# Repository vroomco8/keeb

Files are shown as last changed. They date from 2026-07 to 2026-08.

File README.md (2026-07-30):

# ⌨️ KEYBOARD

*A custom mechanical keyboard, designed from the switches down.*



</div>

---

## Overview

This repository documents the design and build of a fully custom keyboard from scratch.

> [Thought I could get out of my comfort zone and try something I haven't done before. I'm mainly a CS guy, but have always wanted to design and make something for myself!]

Want to note that everything below is entirely conceptual. I have not researched at all about specific electronic parts nor have I explored options with 3d printing and etc. All of the stuff I am saying is coming straight from the little information I know about assembling a keyboard

| | |
|---|---|
| **Layout** | 97% (104-3) |
| **Switches** | Cherry MX (Red) |
| **Case material** | 3D-printed atm, maybe switch to heavy material afterwards |
| **Mounting style** | Tray Mount |
| **Microcontroller** | Raspberry Pi Pico |
| **Firmware** | QMK |

---

## ✨ Features

- [x] RGB Implementation (toggleable)
- [x] Rotary Encoder (Volume, pause/play)
- [x] OLED Screen (Cool displays / Current Spotify / etc...)

---

## 🧩 Design

Currently, I have a Lenovo SK-8815 released in 2004. This thing is older than me (and could be classified as a antique), but it is reliable and I love it. Been using it since 5th grade, and has never failed me. 
However, it can be improved. This organization, HackClub, allows me to sort of improve on its design in ways that I sort of want, through OLED screens and rotary encoders, and more.

For that reason, I want a 100% keyboard with a similar configuration to my old keyboard, but with different switches, RGB(?), wireless, and more if I can fit it within the given timeframe. 
Kinda like this, except the empty space above the numpad has a rotary encoder and an OLED screen


### Some Images





---

## 🗂️ Repository Structure

```
├── pcb/          # KiCad project, schematics, gerbers
├── case/         # CAD files, STLs, technical drawings
├── firmware/     # QMK firmware for the keyboard
├── bom.csv/      # da bill of materials (please approve me)
├── WORKLOG/      # da diary entries of my progress
└── README.md
```

## 🚧 Roadmap

- [x] Making GitHub Repo
- [x] Planning Your Keyboard
- [x] Designing the PCB
- [x] Designing the Case
- [x] Writing Firmware
- [x] Adding Extra Parts
- [ ] Submitting
---

PLEASE APPROVE ME

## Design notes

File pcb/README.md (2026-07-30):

### This folder contains files related to the PCB (KiCad Work)

The final PCB is keeb-v5. All of my CAD files are based off the DRX file generated from the keeb-v5.

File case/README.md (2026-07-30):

### This folder contains all of my CAD files. 

This is the public Onshape file: https://cad.onshape.com/documents/8c70046051d18efdf76ca640/w/53351b508ead0cbaf662196b/e/99ffe23963ec41a247280fbc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

Ignore the missing key. i missed adding it to the PCB model and I got too lazy to get another step file afterwards. Additionally, the holes for the OLED and rotary dial may not be updated, but for the files in these folders they are. 

Also, please note that there were two versions of the CAD. v1 did not work, so v2 was the only one that was uploaded (check worklog as to why ;D)

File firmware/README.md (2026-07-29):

### This folder contains all of the firmware for the keyboard

I used the QMK guide, as it has a lot more support for RGB matrices and encoders, as well as very clear documentation.
Also, I am a complete noob at this, so everything I'm doing is copied straight from the documentation and modified to fit whatever I have.

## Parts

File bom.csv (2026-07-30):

Name | Notes | Qty | Price/Unit | Total | Running Total | Link
Gateron Cherry MX Brown Switches | keyswitches, pack of 108 | 1 | $29.99 | $29.99 | $29.99 | https://www.amazon.com/Zjmehty-Switches-Mechanical-Pre-Lubed-Pin-Enhanced/dp/B0CF8DWDGF?rnid=41941986011
0402 500 Resistor | resistors | 101 | $0.02 | $2.02 | $32.01 | https://jlcpcb.com/partdetail/YAGEO-RT0402FRE07500RL/C6460545
Raspberry Pi Pico | MCU | 1 | $0.99 | $0.99 | $33.00 | https://www.aliexpress.us/item/3256808882158444.html?curPageLogUid=cKROVG7c192z
EC11 Rotary Encoders | for volume, etc | 1 | $1.37 | $1.37 | $34.37 | https://www.aliexpress.us/item/3256805796819763.html?curPageLogUid=JMbjUrnAcT9o
1N4148 diode | capacitors | 3 | $2.02 | $6.06 | $35.74 | https://www.aliexpress.us/item/3256806058794623.html?curPageLogUid=PUp6uTBiT1El
SK6812 mini e LEDs | for each switch, RGB lightin. packs of 100 | 1 | $4.50 | $4.50 | $41.80 | https://www.aliexpress.us/item/3256805007401420.html?curPageLogUid=bFY8ZeYEj1Qn
0.91" OLED | OLED screen | 1 | $2.24 | $2.24 | $46.30 | https://www.aliexpress.us/item/3256809902820804.html?srcSns=sns_Copy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
Durock MX Stab kit | Stabilizers | 1 | $25.99 | $25.99 | $48.54 | https://www.amazon.com/DUROCK-Stabilizers-Translucent-Keyboard-Mechanical/dp/B0B2RVKH2L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
Keycaps | Keycap kit, for 100% | 1 | $17.99 | $17.99 | $74.53 | https://www.amazon.com/Keycaps-Doubleshot-Percent-Mechanical-Keyboard/dp/B0D1QVD55F
PCB | JLCPCB | 1 | $32.30 | $32.30 | $92.52 | quote from uploading
Case | JLCPCB | 1 | $32.96 | $32.96 | $124.82 | quote from uploading
Total |  |  |  |  | $157.78

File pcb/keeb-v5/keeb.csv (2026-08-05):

Id | Designator | Footprint | Quantity | Designation | Supplier and ref
1 | A1 | RaspberryPi_Pico_Common_THT | 1 | RaspberryPi_Pico
2 | C1, C2, C3, C4, C5, C6, C7, C8, C9, C10, C11, C12, C13, C14, C15, C16, C17, C18, C19, C20, C21, C22, C23, C24, C25, C26, C27, C28, C29, C30, C31, C32, C33, C34, C35, C36, C37, C38, C39, C40, C41, C42, C43, C44, C45, C46, C47, C48, C49, C50, C51, C52, C53, C54, C55, C56, C57, C58, C59, C60, C61, C62, C63, C64, C65, C66, C67, C68, C69, C70, C71, C72, C73, C74, C75, C76, C77, C78, C79, C80, C81, C82, C83, C84, C85, C86, C87, C88, C89, C90, C91, C92, C93, C94, C95, C96, C97, C98, C99, C100, C101 | C_0402_1005Metric | 101 | 100nF
3 | D1, D2, D3, D4, D5, D6, D7, D8, D9, D10, D11, D12, D13, D14, D15, D16, D17, D18, D19, D20, D21, D22, D23, D24, D25, D26, D27, D28, D29, D30, D31, D32, D33, D34, D35, D36, D37, D38, D39, D40, D41, D42, D43, D44, D45, D46, D47, D48, D49, D50, D51, D52, D53, D54, D55, D56, D57, D58, D59, D60, D61, D62, D63, D64, D65, D66, D67, D68, D69, D70, D71, D72, D73, D74, D75, D76, D77, D78, D79, D80, D81, D82, D83, D84, D85, D86, D87, D88, D89, D90, D91, D92, D93, D94, D95, D96, D97, D98, D99, D100, D101, D102 | D_DO-35_SOD27_P7.62mm_Horizontal | 102 | 1N4148
4 | LED1, LED2, LED3, LED4, LED5, LED6, LED7, LED8, LED9, LED10, LED11, LED12, LED13, LED14, LED15, LED16, LED17, LED18, LED19, LED20, LED21, LED22, LED23, LED24, LED25, LED26, LED27, LED28, LED29, LED30, LED31, LED32, LED33, LED34, LED35, LED36, LED37, LED38, LED39, LED40, LED41, LED42, LED43, LED44, LED45, LED46, LED47, LED48, LED49, LED50, LED51, LED52, LED53, LED54, LED55, LED56, LED57, LED58, LED59, LED60, LED61, LED62, LED63, LED64, LED65, LED66, LED67, LED68, LED69, LED70, LED71, LED72, LED73, LED74, LED75, LED76, LED77, LED78, LED79, LED80, LED81, LED82, LED83, LED84, LED85, LED86, LED87, LED88, LED89, LED90, LED91, LED92, LED93, LED94, LED95, LED96, LED97, LED98, LED99, LED100, LED101 | LED_6028R | 101 | SK6812MINI-E
5 | R1 | R_0402_1005Metric | 1 | 500
6 | SBackspace1, SEnter1, SLShift1, Sn1, SnEnter1, SnPlus1, SRShift1 | STAB_MX_2u | 7 | MX_stab
7 | SSpace1 | STAB_MX_6.25u | 1 | MX_stab
8 | SW'1, SW,1, SW.1, SW/1, SW1, SW2, SW3, SW4, SW5, SW6, SW7, SW8, SW9, SW10, SW;1, SWa1, SWAsterisk1, SWb1, SWBackspace1, SWc1, SWCapsLock1, SWd1, SWDelete1, SWDown1, SWe1, SWEnd1, SWEnter1, SWEscape1, SWF1, SWF2, SWF3, SWF4, SWf5, SWF6, SWF7, SWF8, SWF9, SWF10, SWF11, SWF12, SWF13, SWForwardSlash1, SWg1, SWh1, SWHome1, SWi1, SWInsert1, SWj1, SWk1, SWl1, SWLAlt1, SWLCtrl1, SWLeft1, SWLShift1, SWLWindows1, SWm1, SWMinus1, SWn1, SWn2, SWn3, SWn4, SWn5, SWn6, SWn7, SWn8, SWn9, SWn10, SWn11, SWnEnter1, SWnMinus1, SWnPeriod1, SWnPlus1, SWNumLock1, SWo1, SWOptions1, SWp1, SWPageDown1, SWPageUp1, SWPlus1, SWq1, SWr1, SWRAlt1, SWRCtrl1, SWRight1, SWRShift1, SWRWindows1, SWs1, SWSpace1, SWt1, SWTab1, SWTilda1, SWu1, SWUp1, SWv1, SWw1, SWx1, SWy1, SWz1, SW[1, SW\1, SW]1 | SW_MX_1u | 101 | SW_Push
9 | SW11 | RotaryEncoder_Alps_EC11E-Switch_Vertical_H20mm | 1 | RotaryEncoder_Switch
10 | U1 | ER_OLEDM0.91_1x-I2C | 1 | ER_OLEDM0.91_1x-I2C

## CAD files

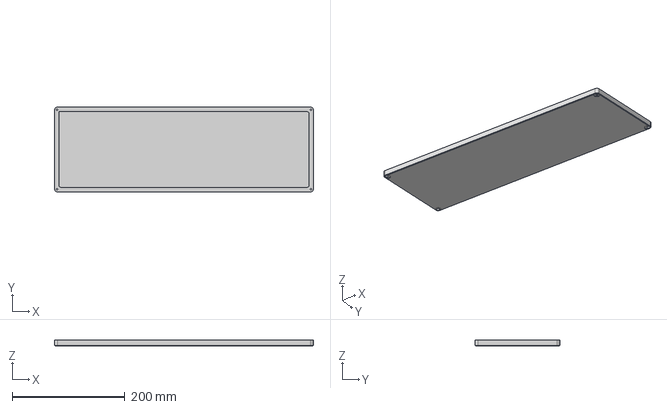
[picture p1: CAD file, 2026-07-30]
case/Keyboard v2 - Bottom Plate.step
459.8 x 150.3 x 10.0 mm

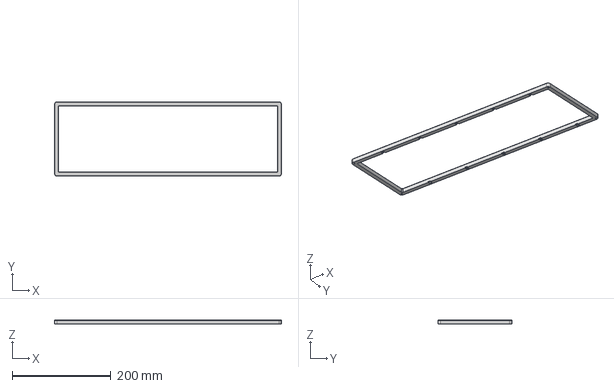
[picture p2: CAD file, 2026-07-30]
case/Keyboard v2 - Top Plate.step
459.8 x 150.3 x 8.50 mm

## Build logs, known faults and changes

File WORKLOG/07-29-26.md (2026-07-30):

### 2026-07-29

~2.5 hrs: Finished up the firmware. Finished bom. Polished PCB.

I realized that 2.25u and 2.75u stabilizers don't exist, so I replaced those with 2u stabilizers on the PCB, and then on the CAD. Also fixed a couple of errors pointed out by the DRC on the PCB. In terms of the CAD, I think I want to see the actual PCB and get a size of it first, before I decide to print out the CAD. I feel that way it would be easier. 
Formatted and updated all of the README.md as well.



Tomorrow, I plan on submitting my git repository.

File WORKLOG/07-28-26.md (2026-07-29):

### 2026-07-28

~2hrs: Worked on the keyboard firmware on the QMK firmware. The RMK firmware didn't have the proper documentation regarding RGB matrix and OLED screens, but the QMK did. It even has a graphical interface!!!

The code is still very rough, will refine over the next couple of days. 





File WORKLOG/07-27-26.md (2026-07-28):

### 226-07-27

~1.5 hrs: Got started working on the firmware

Unfortunately, the guide that was provided does not include support for : LEDs (specifically a chain of them) and an OLED screen. This means that I will have to figure it out without using whatever RMK is, although it is quite unfortunate. 

I will look into/research this in the following couple of days. 


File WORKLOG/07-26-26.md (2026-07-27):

### 2026-07-26

~2hrs: It's on Onshape, at it looks like it fits!  

There are still some tweaks I need to do: 
- add holes for the led screen and rotary encoder
- extend the bottom
- verify whether there are any clearance issues.

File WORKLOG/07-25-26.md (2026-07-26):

### 2026-07-25

~3hrs: "Finished" CAD for the actual keyboard based on my PCB. Now, finished is in quotes because I have no idea whether it will fit or not, because I need to test that in Onshape (D:). Uploading the full PCB model to Fusion 360 blows everything up and causing Fusion to crash over and over. 
Onshape is the only tool which has been able to load the entire PCB on the website. However, I have no idea how to assemble componenets together in onshape, so I gotta watch tutorials. Thats for another day though. Additionally, I don't know how to add a rotary dial and an LED screen on my CAD. 
I don't know if I need to cut out something on my front plate or not, or something similar, but yea thats the predicament I'm in at the moment. I'll add pictures of my Fusion 360 work tomorrows because I kinda accidentally closed Fusion without taking pictures.

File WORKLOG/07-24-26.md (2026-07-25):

### 2026-07-24



~1hr I started working on the actual CAD for the case. Unfortunately, me being a dumbo the schematic generated by ai03 is not the same as the PCB i made on kicad. So, I exported the Kicad files as a drx file and imported into fusion to get the actual plate, and holy that slowed down fusion a lot. It is not happy with me, but whatever. 

Currently, I am building the top plate. Unfortunately, I forgot to hit record on lapse so I have no idea how much time this took, but it felt like forever. I'm just gonna keep it short and keep it at 1 hr.

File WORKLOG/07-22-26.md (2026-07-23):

### 2026-07-22

~2.5hrs: Started working on case. Found a really nice guide on github about designing the case, and I followed it. I verified with the Kicad drx file to check whether everything was the correct size or not, and it appears to be!



Now some issues: 
- I didn't add a hole for the encoder or the OLED screen. This is because the template I used to make the cutouts for each of the keys was provided by https://www.keyboard-layout-editor.com/#/ and https://kbplate.ai03.com/. There isn't a place to add space for a OLED screen or a rotary encoder
- Guide doesn't cover how to add USB holes, or whether to use heatset inserts or not. I just used whatever screws they said to use, which are M2 and M3 screws. This potentially means I need to spend more money on them
- I don't know whether the space inside the case is enough to fit the PCB. I know that the size is right, but the PCB may be bigger or smaller, which means I need to extend the sketch. 

All of these issues just means more work for me, but it's a lot more doable. THANK GOD KICAD CAN EXPORT THINGS INTO A DRX FILE. FUSION 360 IS SO MUCH MORE EASIER TO WORK WITH THAT ONSHAPE. 

Guide I used: https://github.com/axolstudio-ca/Introductory-Guide/wiki/0.-A-Intro-to-Keyboard-Designing

Its very useful in terms of designing and such, giving the proper images.

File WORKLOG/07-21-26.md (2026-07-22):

### 2026-07-21

~10 min: Finalized the PCB. Had some ratsnets issues and such, but all good now (according to DRC) Now getting started on the CAD


I tried starting on the CAD already yesterday, both on Fusion and Onshape. I tried uploading the PCB into Fusion and that thing took hours and hours of loading. I don't even think it loaded, so I gotta learn how to use onshape now. Thats the plan for today!

~1hr 20 min: CAD is easy when you are familiar with the tools. Onshape is slow, messy controls, and also very, very confusing to use. Fusion is so easy, just left clicking a part and adding it to a component. Onshape has different names for things, and also weird UI all over the screen. 
It's so confusing that I had to search up how to resize a rectangle in the sketch tool. Like Fusion makes ts so easy and onshape you gotta use another, completely separate tool just to resize something? 

If only I could upload the PCB CAD model into Fusion 😭

Anyways, I got started on the CAD, and the UI makes me wanna cry. The docs are not that helpful, as they only have text instructions. Images here woulda helped the most. This will definetely be the most time consuming part of the keyboard because I have no idea about the measurements/clearances needed for the PCB. 
All I can rely on is the one screenshot about the "cheatsheet" of different mounts. Bro its just a pic with text on it, it doesn't give any clarification about measurements, how I could implement it, and such. I wish myself good luck in the future. 

I also absolutely abhore the fact that uploading a part onto onshape takes 1. forever and 2. not that straightforward to add to a assembly. This is gonna be the most confusing part of the entire project. 

what also sucks is that i don't have a physical sizing of the board, so i don't know how i could possibly size it to my sepcifications. What if i make it too thick? too thin? can there even be a too thin option? these are all valid concerns in my mind, and all things that could potentially screw up the entire project, but hell everything i've been doing has been off the information that was on the docs, given to me on slack, or my own assumptions. All i could do is walk forward, either to my demise or success. :(



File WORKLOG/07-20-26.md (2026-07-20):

### 2026-07-20

~7.5hrs: Redid all of the wiring such that the LEDs are now on the back of the board. I thought it would be easier to start from scratch. Also got some feedback from slack saying that I should make the +5V trace thicker and also put another trace in the middle so the voltage doesn't drop, which I did. It feels a little bit more messier now, but it is what it is.



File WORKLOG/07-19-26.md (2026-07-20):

### 2026-07-19

~2.5 hrs: Finished the PCB (hopefully) I asked a couple clarifying questions in slack, but I completed all the PCB steps in the actual docs, leaving me with this result: 

My main concern at the moment is the LEDs (as usual). I have 101 LEDs all being wired to one +5V pin on the Pico in a daisy chain format. That means that technically, all 101 pins are being driven from one wire trace, which is not ideal. According to online, it says I need like a 3mm or greater trace to support 101 LEDs in a daisy chain. 
At the moment, I just connected the LEDs so that it somewhat looks like a cycle/loop . I think this is okay, but I'm not too sure so I asked questions about it in slack. 
The keeb-help channel is very, very slow in terms of response times, so I also asked it in the electronics channel. Hopefully someone can answer all of my questions :D

~3.5 hrs: Finished the PCB designing. Added some mountains and space stuff because i thought it was cool. still no response in slack 😭




~2 hrs: Started working on CAD until found issue: The LEDS and the switches are interfering. If I solder the LEDS, the switches have no place in order to sit properly onto the plate. *sigh* This means I need to move the LEDs down such that they are in between each switch so that they could be wired properly. Looking at the PCB, this does appear to be possible. However: I need to work on the wiring again. I don't wanna touch the wiring i spent so long, but i have. This is incredibly unfortunate. 




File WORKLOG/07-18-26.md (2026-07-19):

### 2026-07-18

~9hrs (yes, it was 9hrs you can look at lapse): Finished wiring? No more ratsnets and such, so hopefully finished. I'm gonna keep reading the guide to see what else I need to do.


~1hr verified with the DRC that there are indeed some changes that needed to be made. Errors included some mismatches with the schematic, which I fixed, but there is a warning that I want to look into titled "Silkscreen clipped by solder mask" The silkscreen text is beeing clipped out by the wire. Therefore, either I completely remove the silkscreen text or I edit it such that it fits into board without interfering with the traces. I'm thinking I delete it and add some cool art, I'll look at other people's boards to see what they did. 


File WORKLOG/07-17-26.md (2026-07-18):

### 2026-07-17

~2.5hrs
Worked on tracing. It's a little messy at the moment, but it does work column/row wise. However, I need to route the GND and the LEDs first because that requires the +5V and the GND, which are bigger traces, mm wise. 


~2.5hrs
Back to square one. I messed up, had to delete all the wires. Found a guide, very thankful too daredllama for their feedback on wiring. I did not know about different size wires or the difference between +5, 3.3, etc. Have a game plan for tomorrow, and will work on it!


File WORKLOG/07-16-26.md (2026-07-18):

### 2026-07-16

~2.5hrs  Restarting, but with more planning!

The wiring is hell, so I went back to the drawing board to see if there is a better way to wire everything together this is the way that I decided to do it, so I need to update the schematic and the PCB


Updating PCB schematic: 

I updated the schematic using changing the keys related to the grid and also making sure that everything is named correctly. Also need to ignore the naming conventions, as it kinda got screwed ever with the automatic naming tool. 



~3.5 jrs Updating PCB:

I updated the PCB layout with this new layout. It still is really messy and I need to work out a few kinks here are there. Hopefully it turns out better. Thanks to daredllama, I got a pretty good idea on things I need to improve on, and potentially new methods in terms of wiring (i.e flipping components on the board itself)


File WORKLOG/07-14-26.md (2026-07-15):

### 2026-07-12 

~1.5hrs
Added LED chain, OLED screen, and one rotary encoder to the schematic. Next step is working on the PCB editor itself. Also I completely am doing this from no where, using other people's examples to understand how to wire/connect everything. It still is a little confusing, especially since no one has done a 100% keyboard before with the amount of things that I have on there. 
I hopefully wired everything correctly, and I asked a question in Slack because I wasn't sure whether the LED chain is connected to a 3.3v or 5v (the VDD port on the chain). Hopefully they can clear anything I did wrong easily. 



A big thanks to the brew-keeb project, as that has been my one and only guide light where the documentation falls short. If anyone is reading through this to make their own keyboard, please don't follow my steps. Everything I'm doing comes straight from the documentation/brew-keeb. I have zero experience in PCB design and manufacturing. 

~1.5hrs
Added LED chain, OLED screen, and one rotary encoder to the actual PCB. It looks really, really messy, so hopefully it's not too difficult to wire. 

One thing I am concerned about is the LED chain. At the moment, I am copying what the brew-keeb project did but there are some concerns:

1. The brew-keeb project only uses 22 LEDS. I am using 101 LEDS. This means I probably am going to need significantly more power, which is what another repository, sudo-apt-install-65 does, using a 5v instead of 3.3v. But again, they are using 68 LEDS. I'm almost doubling the amount, so I have no idea whether I have done it correctly or not.
2. The wiring of the LED chain in my mind is like a chain. So, I put the LEDS in like a snake pattern on the PCB. I'm going to try to get started on the wiring, but am saving a copy of my work to the github in case I screw up. 

~1.5hrs
Wiring Hell. I had to rearrange some of the rows in order for it to be "cleanly" wireable on the schematic. This may cause future software problems, but hopefully not. When I get to the columns there's just not enough space for all of the wires to cleanly wire everything up. This may mean I need to rearrage some keys in the schematic, which hopefully isn't too much of a pain




This gonna get real messy real fast.

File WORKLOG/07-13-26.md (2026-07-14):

### 2026-07-12 
~30min
Setup Lapse in order to log a sort of timelapse of my work. Apparently necessary in order for the grant to be approved according to the Slack. Better safe than sorry!

~4hrs
I had to modify the PCB schematic after receiving feedback from Slack. Before I had around 21 columns and 5 rows, meaning I was using 26 GPIO pins, which is basically all of the raspberry GPIO pins. Thanks to some friendly advice on Slack, I was told to modify the grid such that it is a 'square' so I can use the fewest possible GPIO pins.

Now, I have around 13 columns and 8 rows, meaning I'm only using 21 GPIO pins, meaning I have some to spare for the LEDS, a rotary encoder, and an OLED screen (yippee!)

Afterwards, I worked on the PCB itself. Here I really wished that the guide is more specific on certain points. For example, the format. When placing components, I tried my best to make them look aligned and in a grid like shape, but in my mind I'm sure that some of the keys are intersecting. I'm probably going to ask Slack for advice after this, as well as feedback on my current board.


Some concerns: 

1. When modifying the grid, I had to move the entire numpad over to cut the number of columns and squish everything into the space I had. However, I'm trying to think about wiring. Some of the keys are not exactly "nicely placed" in the grid, which in my mind routing may be a little difficult. I may have to restart from scratch in case, but this will be a future problem
2. When adding stabilizers, I realized that a 100% keyboard was quite different from the keyboard used in the guide (who splits their space key into three different space keys???) This means that I have different sized stabilizers for different keys. For example, the space key is 6.25mu, the right shift key is 2.75mu and so on, while the guide only uses 2mu (I'm assuming for simplicity) I'm planning on asking slack if the current way I'm doing it is okay or not.
3. I need to add the rotary encoder and the LEDS (sob). This probably means I will have to go back to the schematic and edit it such that it has those components in. I wish that those objects were in the guide as I went along, but I will probably re-visit them once I have the base model yknow
4. I hate the empty space added by the Raspberry Pi PICO. I wish there was a way to put switches over it so it's nicely hidden OR put like an OLED there so it looks cool. I'll figure something out, so it is a future problem

This is just a quick update for now, maybe will do stuff later today. 
***
~1.5hrs
Alright, as of 11:53 PM, I redid the grid with the alignments. I guess I missed a small part of the guide where it said to make a custom grid such that all the elements are aligned, which actually worked perfectly. Updated grid: 

It doesn't look much different, but zooming in to all of the lines, it is very accurate, and none of the keys overlap with each other which is wonderful. 

Will start the next step (wiring) tomorrow. Hopefully I don't have to redo everything!
So far, this is my main concern, as it is not as clean as the rest of the keyboard

It's seems really messy, hopefully the wiring is manageable.

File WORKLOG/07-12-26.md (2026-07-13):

### 2026-07-12 

~1.5hrs
Started on the KiCAD schematic. Got a basis down, but the guide isn't all that clear about what to do with the stabilizers. Looking at other repos from other people in the Slack, it doesn't appear that they put the stabilizers in their schematics, so I just full on ignored it. Asked a question in slack and hopefully they respond with clarifications on whether my schematic is correct. 


~1.5hrs
Worked on initial draft of the BOM, planning out switches, diodes, etc all according to the guide. Since I'm making a 100% keyboard, I'm aiming for around 104 keys (standard). The Raspberry PI Pico supports that many (11x11 matrix, or less) so I should be fine with that. I planned out a rotary encoder and RGB (Aliexpress for the win)

~1.5hrs
Started the repository. Updated the README about my plans, and started sketching out the type of keyboard I want. Read the full documentation to make sure that I am aware about what the future steps are. I want a 100% keyboard but the guide only outlines a 60% keyboard, which is a little scary but hey I'm doing this to get out of my comfort zone.

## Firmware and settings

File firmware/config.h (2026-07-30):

//OLED settings
#define I2C_DRIVER I2CD1
#define I2C1_SDA_PIN GP27
#define I2C1_SCL_PIN GP28

//RGB
#define WS2812_DI_PIN GP26
#define RGBLIGHT_LED_COUNT 101

#define RGBLIGHT_MODE_RAINBOW_MOOD
#define RGBLIGHT_MODE_RGB_TEST
#define RGBLIGHT_MODE_TWINKLE
#define RGBLIGHT_LIMIT_VAL 100

#define RGBLIGHT_DEFAULT_MODE RGBLIGHT_MODE_RAINBOW_MOOD


//encoders
#define ENCODER_A_PINS { GP21, GP22 }

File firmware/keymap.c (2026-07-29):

// Copyright 2023 QMK
// SPDX-License-Identifier: GPL-2.0-or-later

#include QMK_KEYBOARD_H

const uint16_t PROGMEM keymaps[][8][13] = {
    [0] = LAYOUT(
        KC_ESC,  KC_F1,   KC_F2,   KC_F3,   KC_F4,   KC_F5,   KC_F6,   KC_F7,   KC_F8,   KC_F9,   KC_F10,  KC_F11,  KC_F12, // ROW0
        KC_GRV,  KC_1,    KC_2,    KC_3,    KC_4,    KC_5,    KC_6,    KC_7,    KC_8,    KC_9,    KC_0,    KC_MINS, KC_EQL, // ROW1
        KC_TAB,  KC_Q,    KC_W,    KC_E,    KC_R,    KC_T,    KC_Y,    KC_U,    KC_I,    KC_O,    KC_P,    KC_LBRC, KC_RBRC, // ROW2
        KC_CAPS, KC_A,    KC_S,    KC_D,    KC_F,    KC_G,    KC_H,    KC_J,    KC_K,    KC_L,    KC_SCLN, KC_QUOT, KC_ENT, // ROW3
                 KC_LSFT, KC_Z,    KC_X,    KC_C,    KC_V,    KC_B,    KC_N,    KC_M,    KC_COMM, KC_DOT,  KC_SLSH, KC_RSFT, // ROW4
        KC_LCTL, KC_LGUI, KC_LALT, KC_P0,   KC_P3,   KC_P2,   KC_P1,   KC_NUM,  KC_SPC,  KC_RALT, KC_RGUI, MO(1),   KC_RCTL, // ROW5
        KC_BSLS, KC_MPLY, KC_PPLS, KC_PDOT, KC_P6,   KC_P5,   KC_P4,   KC_PSLS, KC_RIGHT,KC_LEFT, KC_PGDN, KC_END,  KC_DEL, // ROW6
        KC_BSPC,          KC_PMNS, KC_PENT, KC_P9,   KC_P8,   KC_P7,   KC_PAST, KC_DOWN, KC_UP,   KC_PGUP, KC_HOME, KC_INS // ROW7
    ),

    [1] = LAYOUT(
        _______,  _______, _______, _______, _______, _______, _______, _______, _______, _______, _______, _______, _______, // ROW0
        _______,  _______, _______, _______, _______, _______, _______, _______, _______, _______, _______, _______, _______, // ROW1
        _______,  _______, _______, _______, _______, _______, _______, _______, _______, _______, _______, _______, _______, // ROW2
        _______,  _______, _______, _______, _______, _______, _______, _______, _______, _______, _______, _______, _______, // ROW3
                  _______, _______, _______, _______, _______, _______, _______, _______, _______, _______, _______, _______, // ROW4
        _______,  _______, _______, _______, _______, _______, _______, RM_TOGG, _______, _______, _______, _______, _______, // ROW5
        _______,  _______, _______, _______, _______, _______, _______, _______, UG_NEXT, UG_PREV, _______, _______, _______, // ROW6
        _______,           _______, _______, _______, _______, _______, _______, RM_VALD, RM_VALU, _______, _______, _______ // ROW7
    ),

};

#if defined(ENCODER_MAP_ENABLE)
const uint16_t PROGMEM encoder_map[][NUM_ENCODERS][NUM_DIRECTIONS] = {
    [0] = { ENCODER_CCW_CW(KC_VOLD, KC_VOLU)  },
};
#endif

#ifdef OLED_ENABLE
// logo function, mess around in QMK to make a custom logo!
bool oled_task_user(void) {
    // Host Keyboard Layer Status
    oled_write_P(PSTR("Layer: "), false);

    switch (get_highest_layer(layer_state)) {
        case 0:
            oled_write_P(PSTR("Default\n"), false);
            break;
        case 1:
            oled_write_P(PSTR("LEDs\n"), false);
            break;
        default:
            // Or use the write_ln shortcut over adding '\n' to the end of your string
            oled_write_ln_P(PSTR("Undefined"), false);
    }

    // Host Keyboard LED Status
    led_t led_state = host_keyboard_led_state();
    oled_write_P(led_state.num_lock ? PSTR("NUM ") : PSTR("    "), false);
    oled_write_P(led_state.caps_lock ? PSTR("CAP ") : PSTR("    "), false);
    
    return false;
}
#endif

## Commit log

2026-07-13 Create WORKLOG for project tracking
    Added a build diary to track progress and decisions.
2026-07-13 Create WORKLOG.md for project documentation
    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
2026-07-13 Update README.md to reflect work in progress
    Removed placeholder text for PCB and Case sections in README.
2026-07-13 Document work on BOM and keyboard design
    Added another entry for July 12, 2026, detailing work on the BOM and keyboard planning.
2026-07-13 Add PCB image to README
    Added an image to the PCB section in the README.
2026-07-13 Add worklog entry for July 12, 2026
    Document progress on KiCAD schematic, BOM, and repository setup for keyboard project.
2026-07-14 Revise PCB status and update WORKLOG directory
    Updated PCB section to indicate it is currently working and modified the WORKLOG path.
2026-07-14 Add worklog entry for PCB design updates
    Documented work progress on PCB design and modifications, including GPIO pin usage and layout concerns. Added notes on challenges faced and future considerations for components.
2026-07-14 Revise grid alignment and document updates
    Updated the grid alignment and documented changes made to the schematic. Added images to illustrate the updated grid accuracy.
2026-07-14 Document wiring concerns and add images
    Added concerns about wiring cleanliness and images.
2026-07-15 Revise PCB and project status in README
    Updated section headings and added TODO notes for PCB, Case, and Firmware.
2026-07-15 Update worklog with schematic progress and challenges
    Document progress on adding components to the schematic and seeking help on wiring.
2026-07-15 Update WORKLOG with PCB design progress and concerns
    Documented progress on PCB design including LED chain, OLED screen, and rotary encoder. Addressed concerns regarding power requirements and wiring.
2026-07-15 Add README for PCB folder
2026-07-15 Update worklog with LED chain concerns and wiring notes
    Document concerns about LED chain power requirements and wiring challenges. Include images for reference.
2026-07-17 Add work log entry for July 16, 2026
    Documented work progress on July 16, 2026, including planning and schematic updates.
2026-07-18 Revise schematic and PCB layout for better clarity
    Updated schematic and PCB layout with new design considerations and improvements.
2026-07-18 Add work log for tracing progress on July 17, 2026
    Added work log entry for July 17, 2026, detailing tracing progress and requirements for routing GND and LEDs.
2026-07-18 Revise WORKLOG with tracing updates and reflections
    Updated work log with progress and setbacks on tracing. Added images and reflections on wiring feedback.
2026-07-19 Add work log entry for July 18, 2026
    Documented work log for July 18, 2026, detailing 9 hours of work on wiring.
2026-07-19 Document worklog updates and DRC findings
    Verified changes with DRC and addressed schematic mismatches. Considering options for silkscreen text adjustment.
2026-07-20 Add work log entry for July 19, 2026
    Documented work on PCB design and concerns regarding LED wiring.
2026-07-20 Update worklog with PCB design and LED notes
    Documented progress on PCB design and LED wiring concerns.
2026-07-20 Update worklog with PCB and CAD progress
    Documented progress on PCB design and CAD work, noting issues with LED and switch placement.
2026-07-20 Add work log entry for July 20, 2026
    Documented work done on wiring and feedback received for improvements.
2026-07-22 Add work log entry for July 21, 2026
    Documented work log for July 21, 2026, detailing PCB finalization and CAD attempts.
2026-07-22 Update worklog with CAD progress and challenges
    Documented progress on CAD work and challenges faced with Onshape and Fusion. Highlighted issues with UI and the need for better resources.
2026-07-23 Add worklog entry for case design on 2026-07-22
    Documented work on case design, including time spent and issues encountered with cutouts and dimensions.
2026-07-25 Add work log entry for July 24, 2026
    Documented work log for July 24, 2026, detailing CAD work and issues with schematic alignment.
2026-07-26 Add worklog entry for July 25, 2026
    Documented work progress on CAD for keyboard design and issues faced with Fusion 360 and Onshape.
2026-07-28 Update README with details on final PCB and CAD files
    Add additional information about the final PCB and CAD files.
2026-07-28 Create README.md for CAD files documentation
    Added README.md to provide information about CAD files and Onshape link.
2026-07-30 Update README with CAD version notes
    Clarify notes about CAD versions and missing key.
2026-07-30 Update PCB version from keeb-v4 to keeb-v5
2026-07-30 Add work log entry for July 29, 2026
    Documented work progress on firmware and PCB updates, including stabilizer replacements and README formatting.
2026-07-31 Update bom.csv with new components and prices
    [bom.csv]
2026-08-05 Add final pcb README file
